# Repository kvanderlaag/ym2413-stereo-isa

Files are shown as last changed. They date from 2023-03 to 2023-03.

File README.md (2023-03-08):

# OPLL Stereo ISA Sound Card

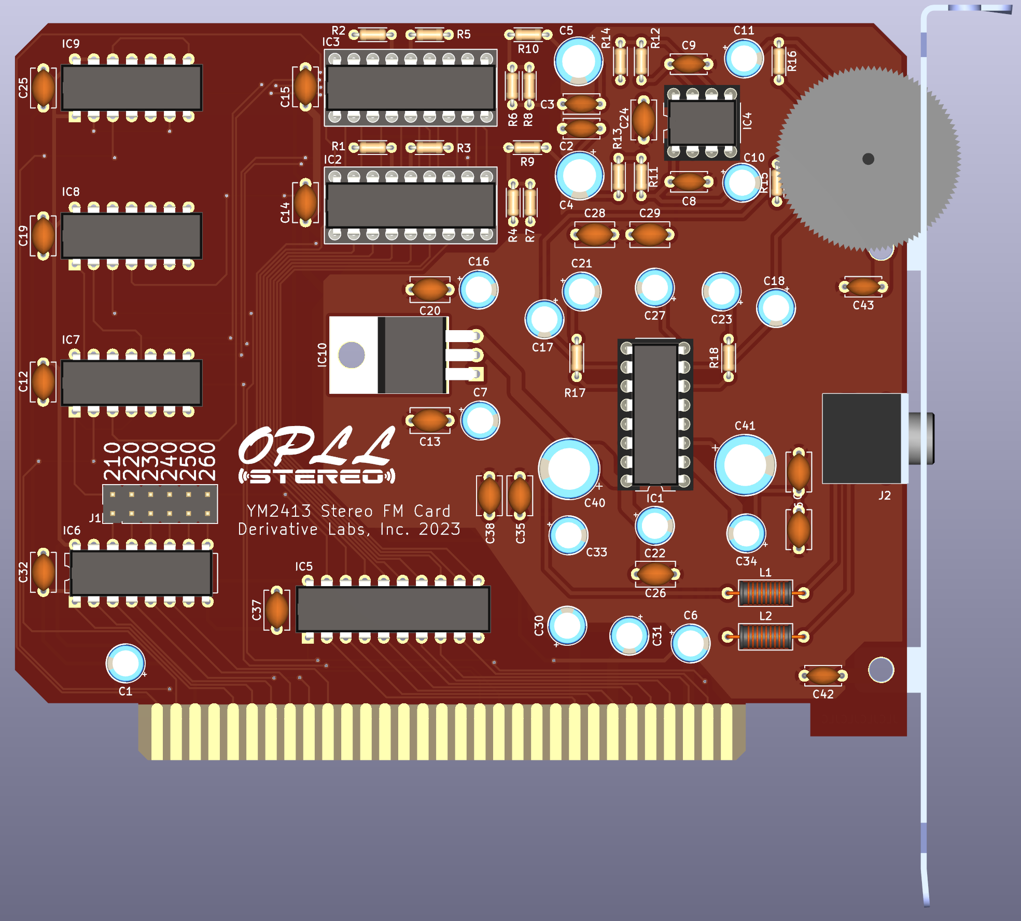
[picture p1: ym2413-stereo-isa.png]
Straight-on view of the board

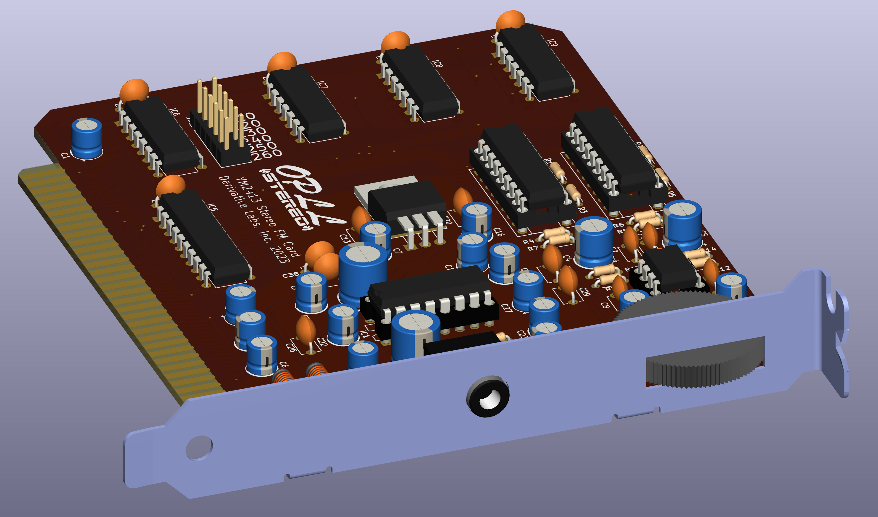
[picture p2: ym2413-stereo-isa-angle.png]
Angled view of the board

 
## What is this?

It's an ISA sound card that uses two YM2413s (otherwise known as the OPLL) in stereo to make noise.

## Okay, but why?

I don't know, you tell me. You're the one looking at this repository.

## What can I do with it?

Whatever you want, I'm not your dad.

## Okay, but I mean, what software can I run with it?

If you're asking what software supports it, the answer is "none."

## Then I ask again: why?

Because there weren't enough weird sound cards for the PC, apparently.

## How do I program it?

The jumper block lets you select a base address from 210h, 220h, 230h, 240h, 250h, or 260h. Assuming you have the base address set at 210h, the left channel OPLL lives on 210h-201h, and the right channel OPLL lives on 212h-213h. Write to the first address for a chip to select a register in the OPLL, and write to the second address to write data to that register.

That's it. That's the card.

## Okay, but how do I program the OPLL?

I actually have no idea. You'll want to refer to the datasheet, which is in this repository as "YM2413 Datasheet.pdf". Pages 4 and 5 contain the register map, and register data. In short, the OPLL is a cut-rate OPL that was originally intended for cheap-ass pachinko machines and other things that make annoying noises at you to get your attention. I think it also does Teletext, if that floats your boat for some reason. It supports up to nine voices, but only one of them is user-programmable. The rest you get to choose from a bunch of patches that live in ROM. Please let me know if you write anything interesting for this. I sure haven't yet.

## What if I just want to build one?

Now it's my turn to ask: why? Either way, OPLL-Stereo.zip is in the "gerbil" folder; you should be able to fire that off to JLCPCB and select "choose location" for the order number; the gerbers are all set up for that. The BOM is in a CSV file here with DigiKey links to the parts the board was designed for. If you find a 10K audio taper pot that fits that footprint, please let me know; I'm using a 50K with a 15K fixed resistor in parallel right now and it kind of sucks. Everything is pretty basic as far as parts go; a couple of the logic chips have been in shortage, but you should be able to substitute HCTs for the LSes if you need to, and everything should be actively available. The bracket is a Keystone 9202, and screws are listed. You'll need to drill a hole for the audio jack (I've been using a 9/32" bit) and cut a slot for a volume wheel, if you want to add one. There's a 3D-printable volume knob and card bracket in the `Mechanical` folder if you want to go that route. The volume knob attaches with an M1.4x0.3 5mm machine screw.

## I built one and it doesn't work! What the hell, man?

I'm not surprised.

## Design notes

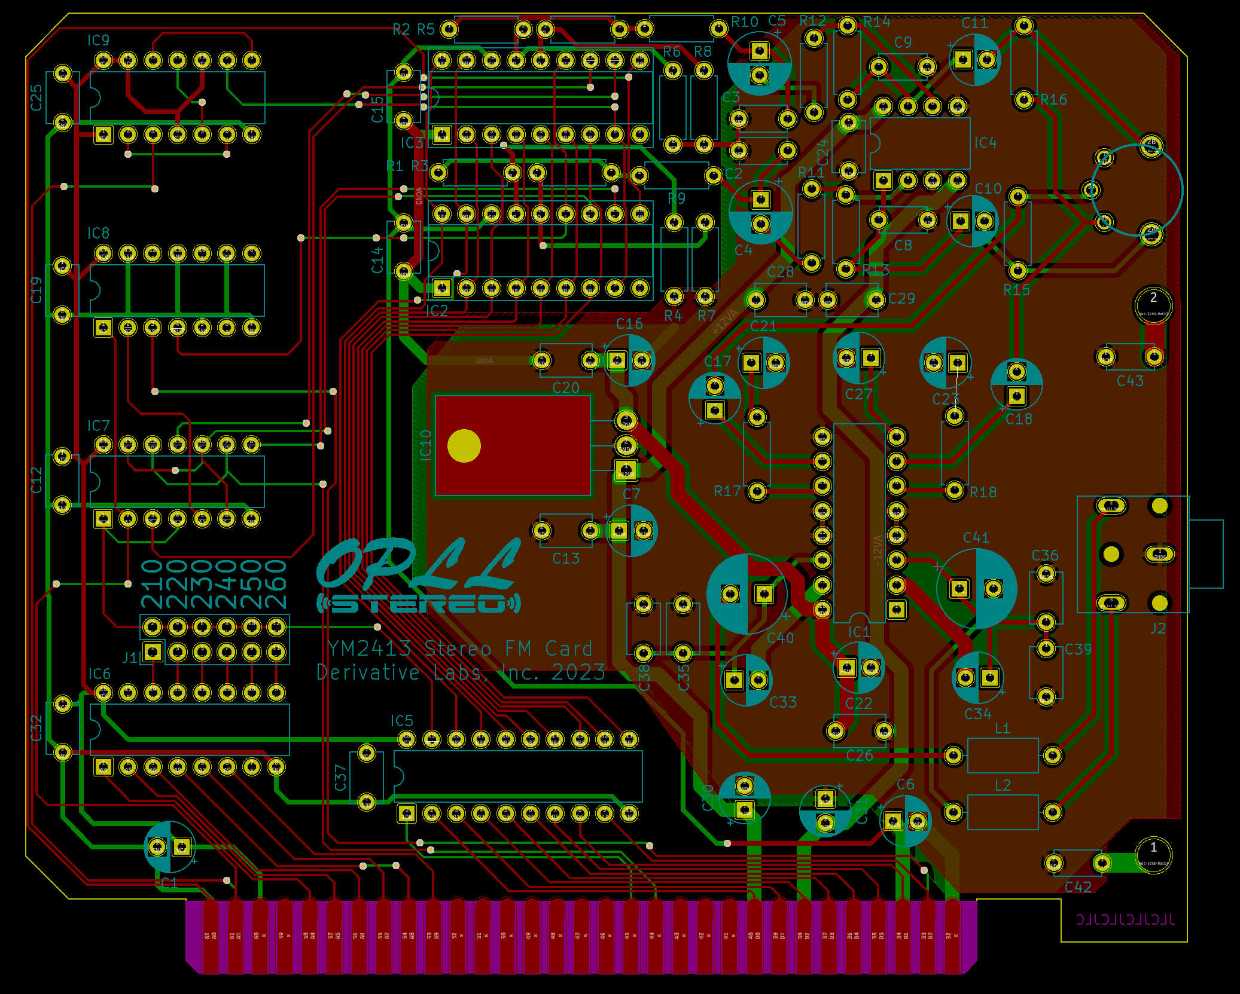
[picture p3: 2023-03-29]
ym2413-stereo-isa-board.png

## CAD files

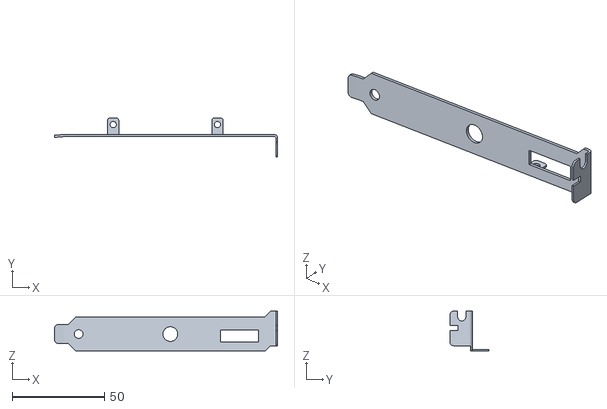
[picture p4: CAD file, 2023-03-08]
Mechanical/YM2413-Stereo-Card-Bracket.stl
120.9 x 21.1 x 21.6

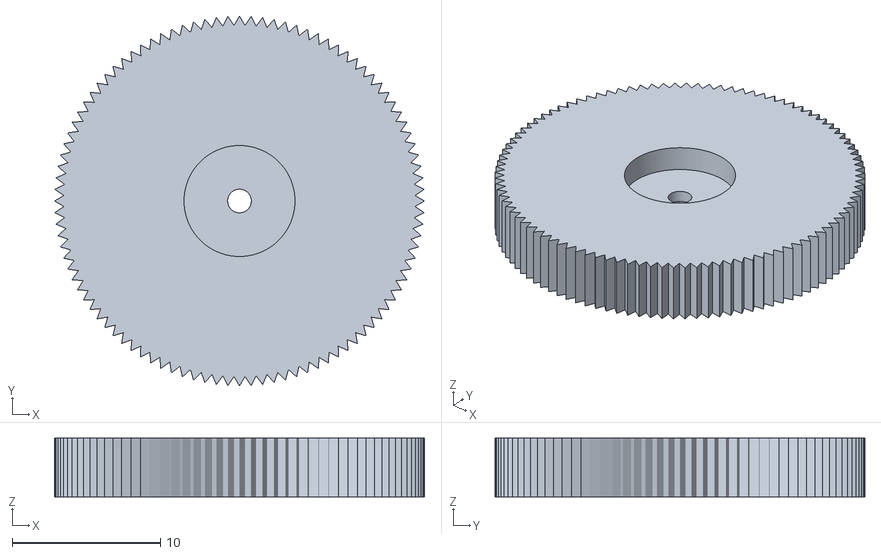
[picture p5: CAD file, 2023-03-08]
Mechanical/YM2413-Stereo-Volume-Knob-Recessed.stl
25.0 x 25.0 x 3.98

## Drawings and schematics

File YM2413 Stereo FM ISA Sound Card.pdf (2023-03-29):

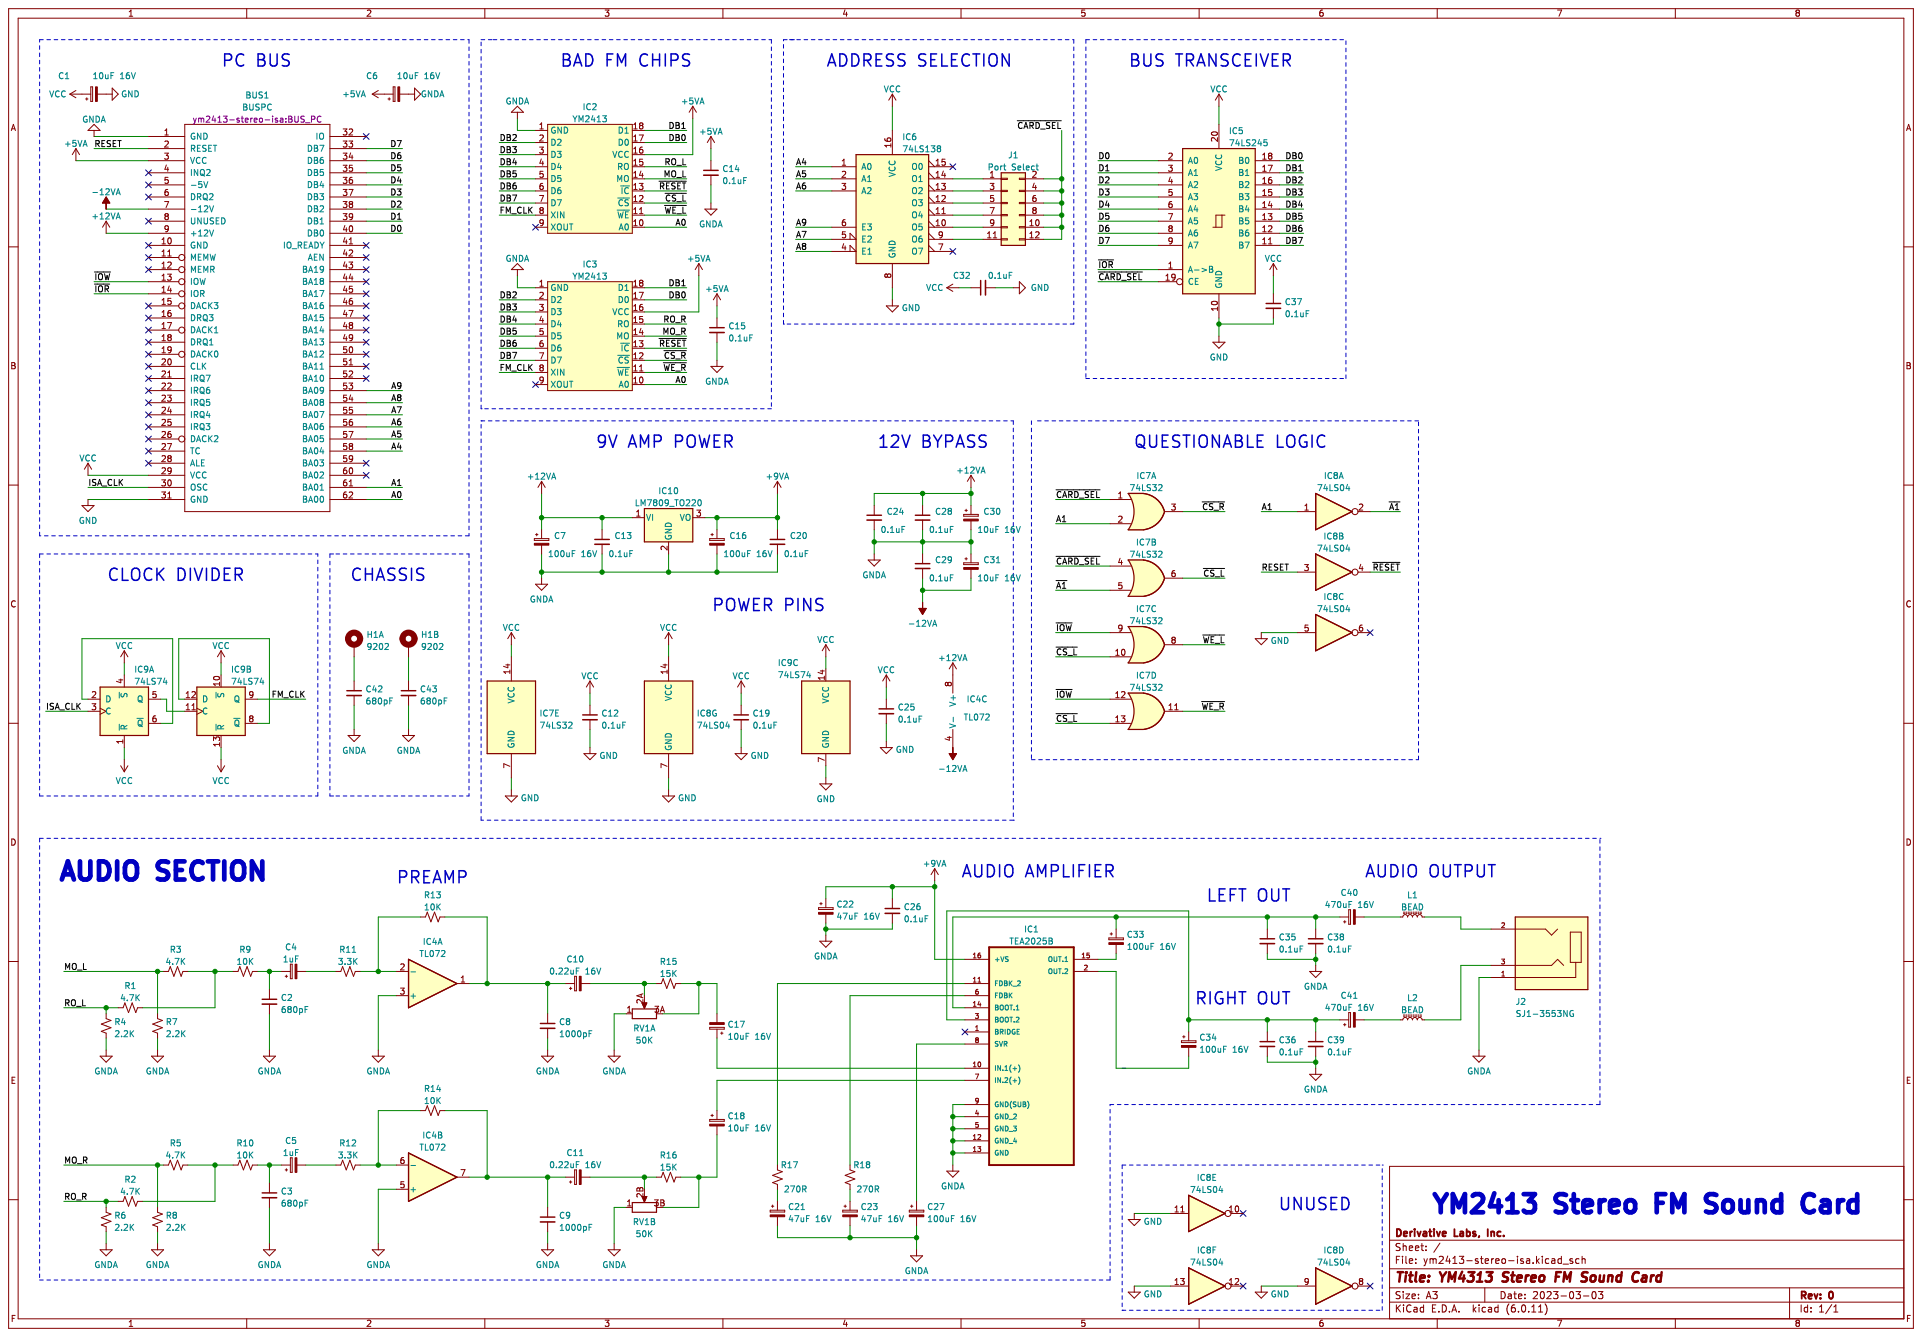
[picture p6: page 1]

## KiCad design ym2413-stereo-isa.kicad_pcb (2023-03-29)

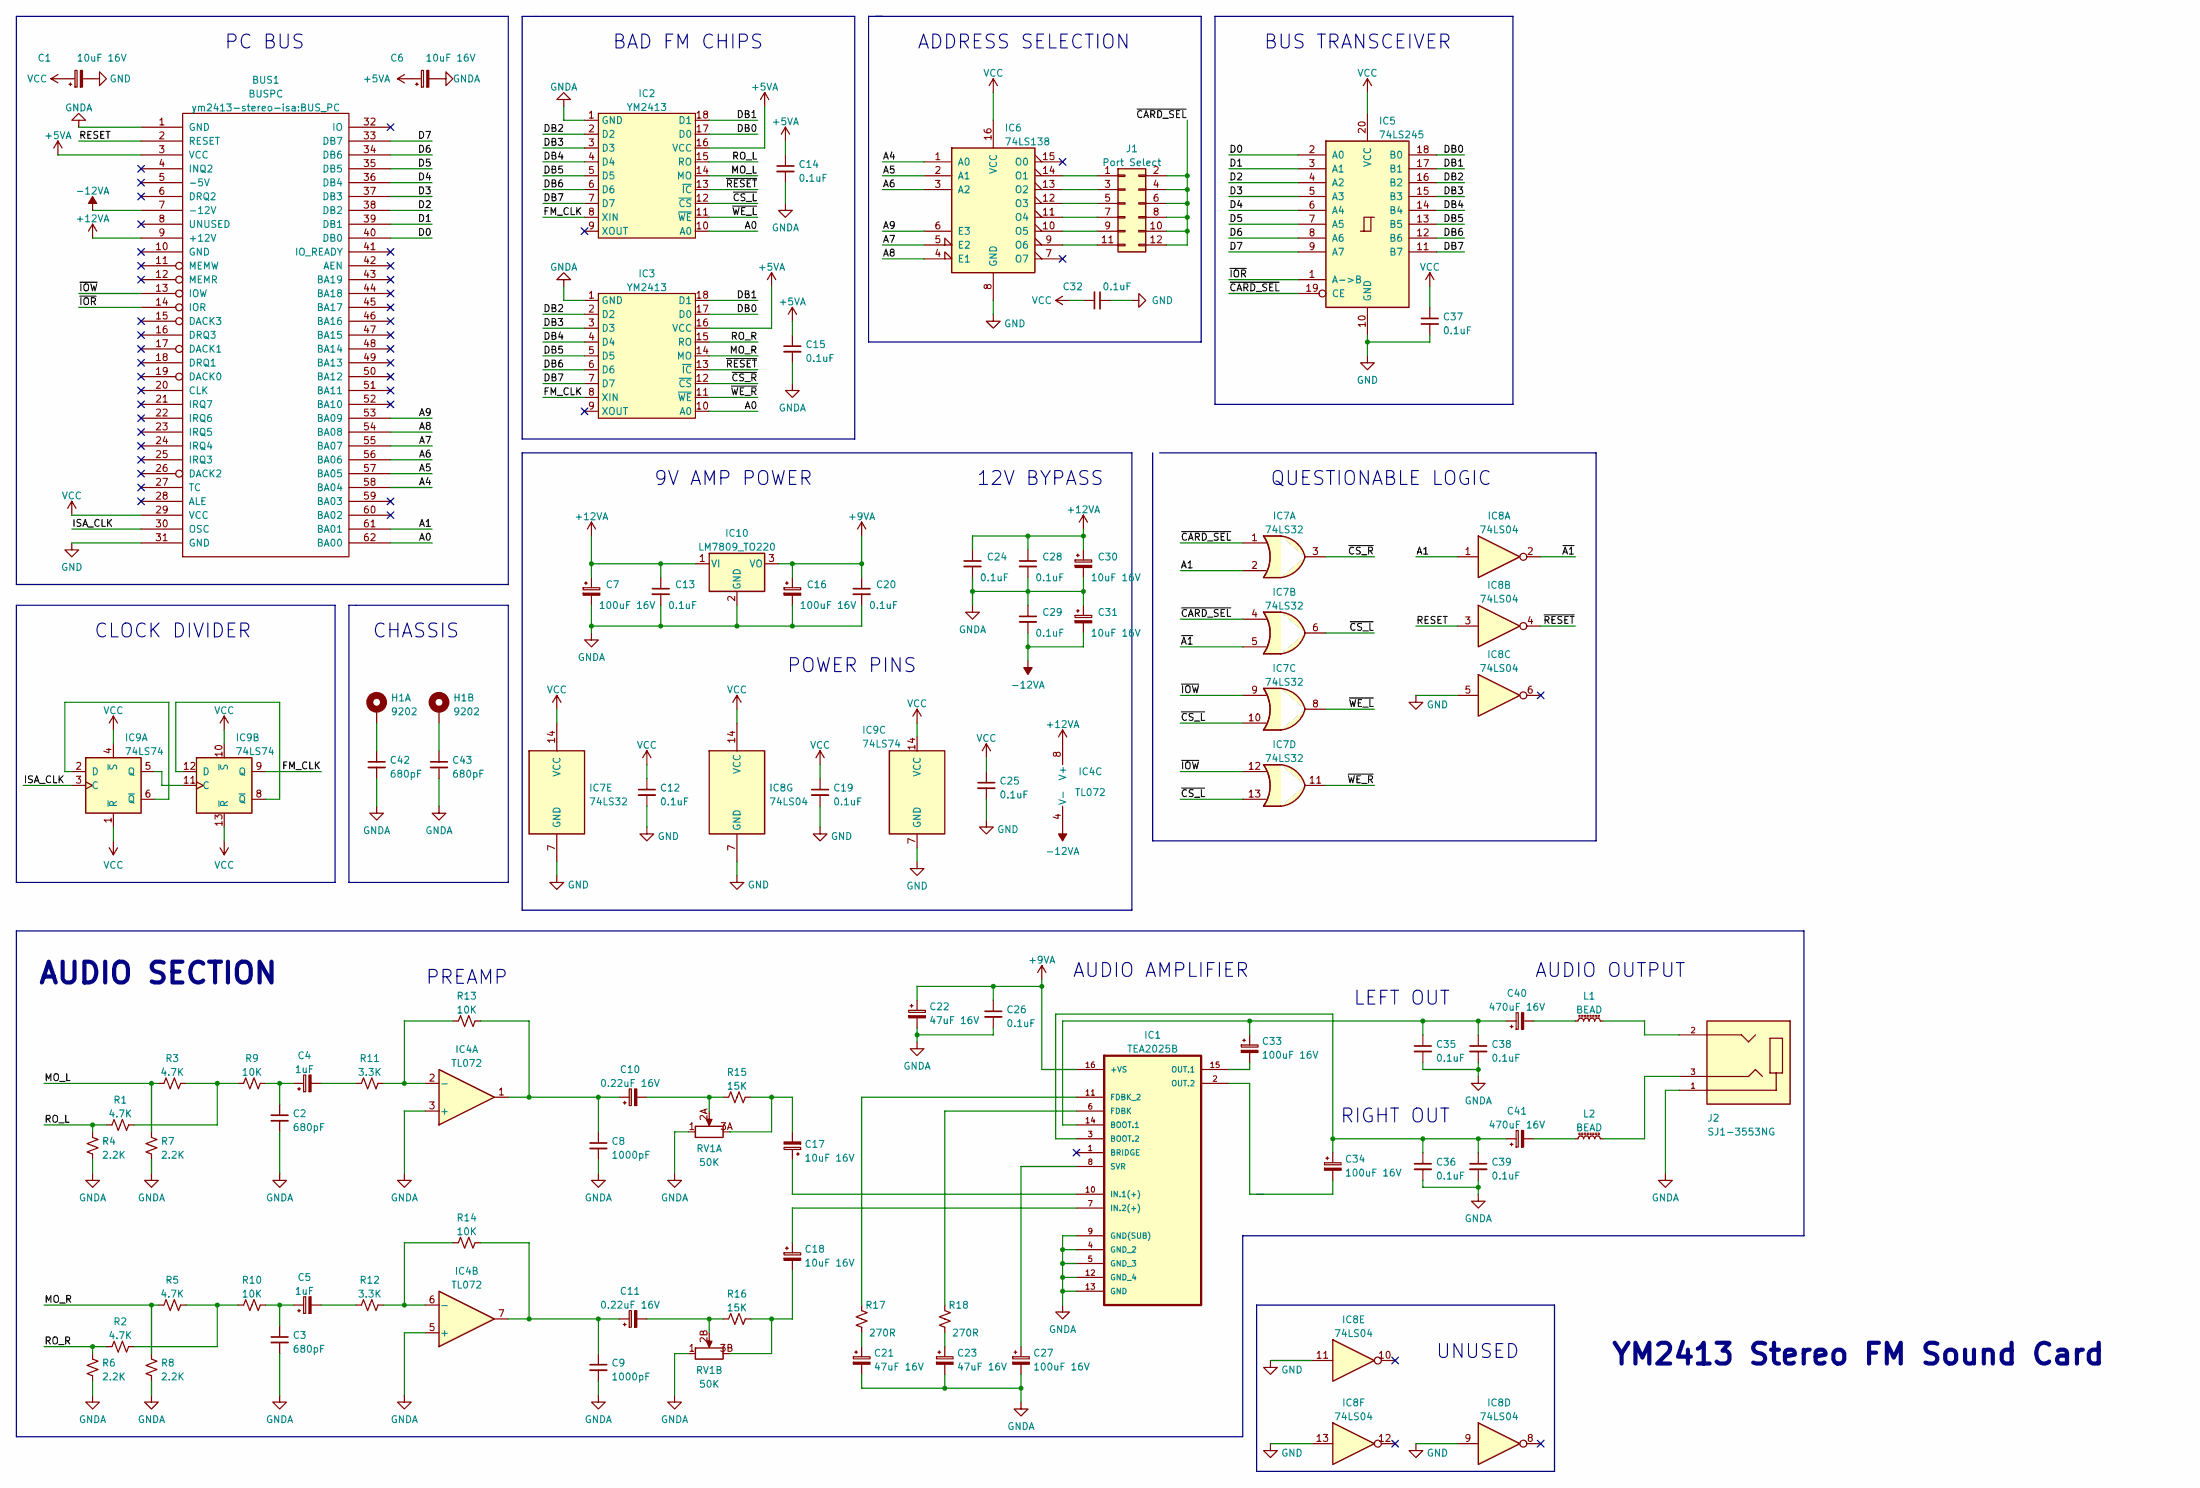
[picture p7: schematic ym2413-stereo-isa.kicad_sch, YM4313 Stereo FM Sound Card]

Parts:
BUS1: BUSPC; BUS_PC
C1, C6, C17, C18, C30, C31: 10uF 16V; CP_Radial_D5.0mm_P2.50mm
C2, C3, C42, C43: 680pF; C_Disc_D4.7mm_W2.5mm_P5.00mm
C4, C5: 1uF; CP_Radial_D6.3mm_P2.50mm
C7, C16, C27, C33, C34: 100uF 16V; CP_Radial_D5.0mm_P2.50mm
C8, C9: 1000pF; C_Disc_D4.7mm_W2.5mm_P5.00mm
C10, C11: 0.22uF 16V; CP_Radial_D5.0mm_P2.50mm
C12, C13, C14, C15, C19, C20, C24, C25, C26, C28, C29, C32, C35, C36, C37, C38, C39: 0.1uF; C_Disc_D5.1mm_W3.2mm_P5.00mm
C21, C22, C23: 47uF 16V; CP_Radial_D5.0mm_P2.50mm
C40, C41: 470uF 16V; CP_Radial_D8.0mm_P3.50mm
H1: 9202; MNT_KEYSTONE_9202
IC1: TEA2025B; DIP-16_W7.62mm; MPN TEA2025B
IC2, IC3: YM2413; DIP-18_W7.62mm_Socket
IC4: TL072; DIP-8_W7.62mm
IC5: 74LS245; DIP-20_W7.62mm
IC6: 74LS138; DIP-16_W7.62mm
IC7: 74LS32; DIP-14_W7.62mm
IC8: 74LS04; DIP-14_W7.62mm
IC9: 74LS74; DIP-14_W7.62mm
IC10: LM7809_TO220; TO-220-3_Horizontal_TabDown
J1: Port Select; PinHeader_2x06_P2.54mm_Vertical
J2: SJ1-3553NG; CUI_SJ1-3553NG
L1, L2: BEAD; L_Axial_L7.0mm_D3.3mm_P10.16mm_Horizontal_Fastron_MICC
R1, R2, R3, R5: 4.7K; R_Axial_DIN0204_L3.6mm_D1.6mm_P5.08mm_Horizontal
R4, R6, R7, R8: 2.2K; R_Axial_DIN0204_L3.6mm_D1.6mm_P5.08mm_Horizontal
R9, R10, R13, R14: 10K; R_Axial_DIN0204_L3.6mm_D1.6mm_P5.08mm_Horizontal
R11, R12: 3.3K; R_Axial_DIN0204_L3.6mm_D1.6mm_P5.08mm_Horizontal
R15, R16: 15K; R_Axial_DIN0204_L3.6mm_D1.6mm_P5.08mm_Horizontal
R17, R18: 270R; R_Axial_DIN0204_L3.6mm_D1.6mm_P5.08mm_Horizontal
RV1: 50K; GB_BOURNS_PDB08-DUAL

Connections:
+5VA: BUS1.3 (VCC), C6.1, C14.1, C15.1, IC2.16 (VCC), IC3.16 (VCC)
+9VA: C16.1, C20.1, C22.1, C26.1, IC1.16 (+VS), IC10.3 (VO)
+12VA: BUS1.9 (+12V), C7.1, C13.1, C24.1, C28.1, C30.1, IC4.8 (V+), IC10.1 (VI)
-12VA: BUS1.7 (-12V), C29.2, C31.2, IC4.4 (V-)
/A0: BUS1.62 (BA00), IC2.10 (A0), IC3.10 (A0)
/A1: BUS1.61 (BA01), IC7.2, IC8.1
/A4: BUS1.58 (BA04), IC6.1 (A0)
/A5: BUS1.57 (BA05), IC6.2 (A1)
/A6: BUS1.56 (BA06), IC6.3 (A2)
/A7: BUS1.55 (BA07), IC6.5 (E2)
/A8: BUS1.54 (BA08), IC6.4 (E1)
/A9: BUS1.53 (BA09), IC6.6 (E3)
/D0: BUS1.40 (DB0), IC5.2 (A0)
/D1: BUS1.39 (DB1), IC5.3 (A1)
/D2: BUS1.38 (DB2), IC5.4 (A2)
/D3: BUS1.37 (DB3), IC5.5 (A3)
/D4: BUS1.36 (DB4), IC5.6 (A4)
/D5: BUS1.35 (DB5), IC5.7 (A5)
/D6: BUS1.34 (DB6), IC5.8 (A6)
/D7: BUS1.33 (DB7), IC5.9 (A7)
/DB0: IC2.17 (D0), IC3.17 (D0), IC5.18 (B0)
/DB1: IC2.18 (D1), IC3.18 (D1), IC5.17 (B1)
/DB2: IC2.2 (D2), IC3.2 (D2), IC5.16 (B2)
/DB3: IC2.3 (D3), IC3.3 (D3), IC5.15 (B3)
/DB4: IC2.4 (D4), IC3.4 (D4), IC5.14 (B4)
/DB5: IC2.5 (D5), IC3.5 (D5), IC5.13 (B5)
/DB6: IC2.6 (D6), IC3.6 (D6), IC5.12 (B6)
/DB7: IC2.7 (D7), IC3.7 (D7), IC5.11 (B7)
/FM_CLK: IC2.8 (XIN), IC3.8 (XIN), IC9.9 (Q)
/ISA_CLK: BUS1.30 (OSC), IC9.3 (C)
/MO_L: IC2.14 (MO), R3.2, R7.1
/MO_R: IC3.14 (MO), R5.2, R8.1
/RESET: BUS1.2 (RESET), IC8.3
/RO_L: IC2.15 (RO), R1.2, R4.1
/RO_R: IC3.15 (RO), R2.2, R6.1
/~A1: IC7.5, IC8.2
/~CARD_SEL: IC5.19 (CE), IC7.1, IC7.4, J1.2, J1.4, J1.6, J1.8, J1.10, J1.12
/~CS_L: IC2.12 (~CS), IC7.6, IC7.10, IC7.13
/~CS_R: IC3.12 (~CS), IC7.3
/~IOR: BUS1.14 (IOR), IC5.1 (A->B)
/~IOW: BUS1.13 (IOW), IC7.9, IC7.12
/~RESET: IC2.13 (~IC), IC3.13 (~IC), IC8.4
/~WE_L: IC2.11 (~WE), IC7.8
/~WE_R: IC3.11 (~WE), IC7.11
GND: BUS1.31 (GND), C1.2, C12.2, C19.2, C25.2, C32.2, C37.2, IC5.10 (GND), IC6.8 (GND), IC7.7 (GND), IC8.5, IC8.7 (GND), IC8.9, IC8.11, IC8.13, IC9.7 (GND)
GNDA: BUS1.1 (GND), C2.2, C3.2, C6.2, C7.2, C8.2, C9.2, C13.2, C14.2, C15.2, C16.2, C20.2, C21.2, C22.2, C23.2, C24.2, C26.2, C27.2, C28.2, C29.1, C30.2, C31.1, C35.2, C36.2, C38.2, C39.2, C42.2, C43.2, IC1.4 (GND_2), IC1.5 (GND_3), IC1.9 (GND(SUB)), IC1.12 (GND_4), IC1.13 (GND), IC2.1 (GND), IC3.1 (GND), IC4.3 (+), IC4.5 (+), IC10.2 (GND), J2.1, R4.2, R6.2, R7.2, R8.2, RV1.1
unnamed: C2.1, C4.1, R9.1
unnamed: C3.1, C5.1, R10.1
unnamed: C4.2, R11.2
unnamed: C5.2, R12.2
unnamed: C8.1, C10.1, IC4.1, R13.1
unnamed: C10.2, R15.2, RV1.2A
unnamed: C9.1, C11.1, IC4.7, R14.1
unnamed: C11.2, R16.2, RV1.2B
unnamed: C17.1, IC1.10 (IN.1(+))
unnamed: C17.2, R15.1, RV1.3A
unnamed: C18.1, IC1.7 (IN.2(+))
unnamed: C18.2, R16.1, RV1.3B
unnamed: C21.1, R17.2
unnamed: C23.1, R18.2
unnamed: C27.1, IC1.8 (SVR)
unnamed: C33.1, C35.1, C38.1, C40.1, IC1.14 (BOOT.1)
unnamed: C33.2, IC1.15 (OUT.1)
unnamed: C34.1, C36.1, C39.1, C41.1, IC1.3 (BOOT.2)
unnamed: C34.2, IC1.2 (OUT.2)
unnamed: C40.2, L1.1
unnamed: C41.2, L2.1
unnamed: C42.1, H1.1
unnamed: C43.1, H1.2
unnamed: IC1.6 (FDBK), R18.1
unnamed: IC1.11 (FDBK_2), R17.1
unnamed: IC4.2 (-), R11.1, R13.2
unnamed: IC4.6 (-), R12.1, R14.2
unnamed: IC6.9 (O6), J1.11
unnamed: IC6.10 (O5), J1.9
unnamed: IC6.11 (O4), J1.7
unnamed: IC6.12 (O3), J1.5
unnamed: IC6.13 (O2), J1.3
unnamed: IC6.14 (O1), J1.1
unnamed: IC9.2 (D), IC9.6 (~Q)
unnamed: IC9.5 (Q), IC9.11 (C)
unnamed: IC9.8 (~Q), IC9.12 (D)
unnamed: J2.2, L1.2
unnamed: J2.3, L2.2
unnamed: R1.1, R3.1, R9.2
unnamed: R2.1, R5.1, R10.2
VCC: BUS1.29 (VCC), C1.1, C12.1, C19.1, C25.1, C32.1, C37.1, IC5.20 (VCC), IC6.16 (VCC), IC7.14 (VCC), IC8.14 (VCC), IC9.1 (~R), IC9.4 (~S), IC9.10 (~S), IC9.13 (~R), IC9.14 (VCC)

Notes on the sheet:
CHASSIS
POWER PINS
LEFT OUT
PREAMP
BUS TRANSCEIVER
CLOCK DIVIDER
AUDIO AMPLIFIER
AUDIO SECTION
RIGHT OUT
12V BYPASS
PC BUS
9V AMP POWER
BAD FM CHIPS
ADDRESS SELECTION
YM2413 Stereo FM Sound Card
AUDIO OUTPUT
QUESTIONABLE LOGIC
UNUSED

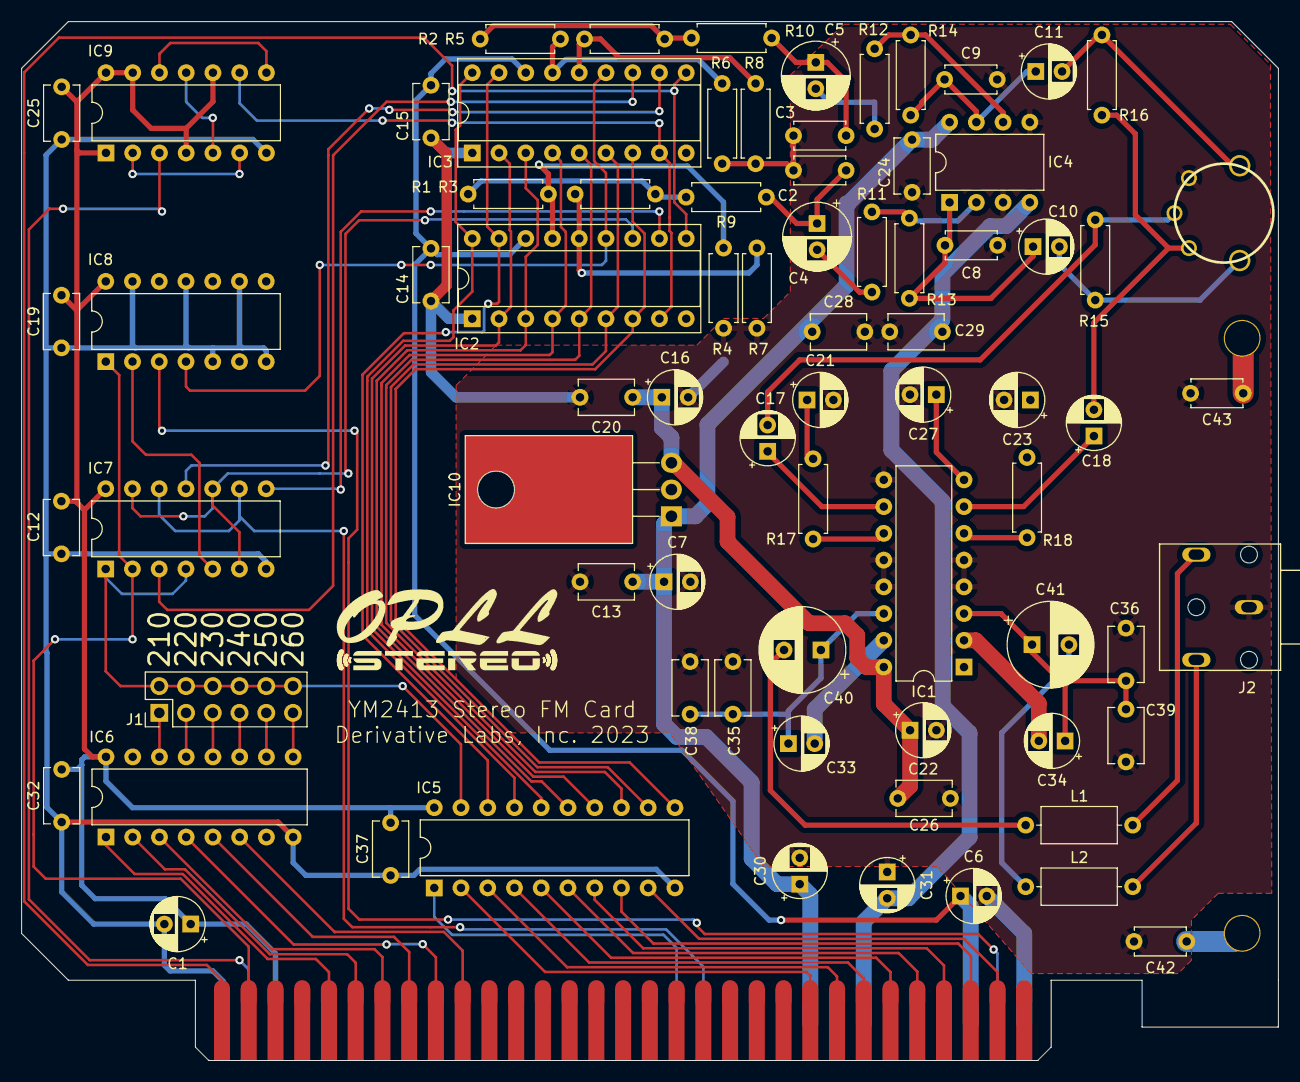
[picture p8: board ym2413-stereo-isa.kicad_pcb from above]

Board: 2 copper layers, 119.4 x 98.7 mm, 78 parts (0 on the bottom side), 87 nets.

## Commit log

2023-03-04 Board Rev. 0
    [ym2413-stereo-isa-B_Cu.gbr, ym2413-stereo-isa-B_Mask.gbr, ym2413-stereo-isa-B_Paste.gbr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]
2023-03-08 Relocate volume pot and output jack; update gerbers; add CAD models
    [YM2413-Stereo-Card-Bracket.stl, YM2413-Stereo-Volume-Knob-Recessed.stl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]
2023-03-08 fix X offset of bracket model
    [ym2413-stereo-isa.kicad_pcb]
2023-03-29 correct capacitor footprint; move voltage divider; flip coupling caps
    [ym2413-stereo-isa-B_Cu.gbr, ym2413-stereo-isa-B_Mask.gbr, ym2413-stereo-isa-B_Paste.gbr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]
